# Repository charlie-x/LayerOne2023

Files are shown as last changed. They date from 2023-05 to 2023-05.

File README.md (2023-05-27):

# LayerOne2023

# Hardware

PIC16F1455

WS2812B/SK6812

# Software Needed

Microchip MPLAB 6.10

  https://www.microchip.com/en-us/tools-resources/develop/mplab-x-ide
  
XC8 2.41

  https://www.microchip.com/en-us/tools-resources/develop/mplab-xc-compilers/downloads-documentation#XC8

# DFU mode bootloader

 Badge has a DFU loader, hold the button down while plugging in USB should appear as device
 In Windows use ZADIG https://github.com/pbatard/libwdi/releases/download/v1.5.0/zadig-2.8.exe to change the driver to WinUSB device ID will be 1209:2002
 Modified Bootloader code is at https://github.com/charlie-x/PIC16F1455_Bootloader full fork https://github.com/charlie-x/PIC16F1455_Bootloader with tools
 
# dfu-utils to upload to badge
 
 convert hex file from Bootloader MPLAB project ( must use the HTxxxxxx_BootLoader version )
 
 get 454hex2dfu here https://github.com/charlie-x/PIC16F1-USB-DFU-Bootloader/tree/master/tools 
 
  454hex2dfu input.hex OKBBPIC_firmware.production.dfu
 
 put badge in DFU mode by holding button down and plugging into usb. (only when L1 bootloader is installed, if its overwritten you have to reinstall it with a PIC programmer like the pickkit3)
 
  dfu-util  -l -D OKBBPIC_firmware.production.dfu -R
 
# Optional Programmer

Pickit 3 or better , Pickit 2 supports CU with 3rd party sofware ,3 or 4 is recommended.

# badge competition

there is a very partial rubberducky 2.0 script commented out in the code, whoever makes it run duckyscript first, wins the single prize. claim with charliex, mmca or datagram.

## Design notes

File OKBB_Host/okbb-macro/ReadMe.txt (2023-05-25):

================================================================================
    MICROSOFT FOUNDATION CLASS LIBRARY : okbb-macro Project Overview
===============================================================================

The application wizard has created this okbb-macro application for
you.  This application not only demonstrates the basics of using the Microsoft
Foundation Classes but is also a starting point for writing your application.

This file contains a summary of what you will find in each of the files that
make up your okbb-macro application.

okbb-macro.vcxproj
    This is the main project file for VC++ projects generated using an application wizard.
    It contains information about the version of Visual C++ that generated the file, and
    information about the platforms, configurations, and project features selected with the
    application wizard.

okbb-macro.vcxproj.filters
    This is the filters file for VC++ projects generated using an Application Wizard. 
    It contains information about the assciation between the files in your project 
    and the filters. This association is used in the IDE to show grouping of files with
    similar extensions under a specific node (for e.g. ".cpp" files are associated with the
    "Source Files" filter).

okbb-macro.h
    This is the main header file for the application.  It includes other
    project specific headers (including Resource.h) and declares the
    COKBBmacroApp application class.

okbb-macro.cpp
    This is the main application source file that contains the application
    class COKBBmacroApp.

okbb-macro.rc
    This is a listing of all of the Microsoft Windows resources that the
    program uses.  It includes the icons, bitmaps, and cursors that are stored
    in the RES subdirectory.  This file can be directly edited in Microsoft
    Visual C++. Your project resources are in 1033.

res\okbb-macro.ico
    This is an icon file, which is used as the application's icon.  This
    icon is included by the main resource file okbb-macro.rc.

res\okbbmacro.rc2
    This file contains resources that are not edited by Microsoft
    Visual C++. You should place all resources not editable by
    the resource editor in this file.

/////////////////////////////////////////////////////////////////////////////

The application wizard creates one dialog class:

okbb-macroDlg.h, okbb-macroDlg.cpp - the dialog
    These files contain your CokbbmacroDlg class.  This class defines
    the behavior of your application's main dialog.  The dialog's template is
    in okbb-macro.rc, which can be edited in Microsoft Visual C++.

/////////////////////////////////////////////////////////////////////////////

Help Support:

hlp\okbbmacro.hhp
    This file is a help project file. It contains the data needed to
    compile the help files into a .chm file.

hlp\okbbmacro.hhc
    This file lists the contents of the help project.

hlp\okbbmacro.hhk
    This file contains an index of the help topics.

hlp\afxcore.htm
    This file contains the standard help topics for standard MFC
    commands and screen objects. Add your own help topics to this file.

makehtmlhelp.bat
    This file is used by the build system to compile the help files.

hlp\Images\*.gif
    These are bitmap files required by the standard help file topics for
    Microsoft Foundation Class Library standard commands.

/////////////////////////////////////////////////////////////////////////////

Other standard files:

StdAfx.h, StdAfx.cpp
    These files are used to build a precompiled header (PCH) file
    named okbb-macro.pch and a precompiled types file named StdAfx.obj.

Resource.h
    This is the standard header file, which defines new resource IDs.
    Microsoft Visual C++ reads and updates this file.

okbb-macro.manifest
	Application manifest files are used by Windows XP to describe an applications
	dependency on specific versions of Side-by-Side assemblies. The loader uses this
	information to load the appropriate assembly from the assembly cache or private
	from the application. The Application manifest  maybe included for redistribution
	as an external .manifest file that is installed in the same folder as the application
	executable or it may be included in the executable in the form of a resource.
/////////////////////////////////////////////////////////////////////////////

Other notes:

The application wizard uses "TODO:" to indicate parts of the source code you
should add to or customize.

If your application uses MFC in a shared DLL, you will need
to redistribute the MFC DLLs. If your application is in a language
other than the operating system's locale, you will also have to
redistribute the corresponding localized resources MFC100XXX.DLL.
For more information on both of these topics, please see the section on
redistributing Visual C++ applications in MSDN documentation.

/////////////////////////////////////////////////////////////////////////////

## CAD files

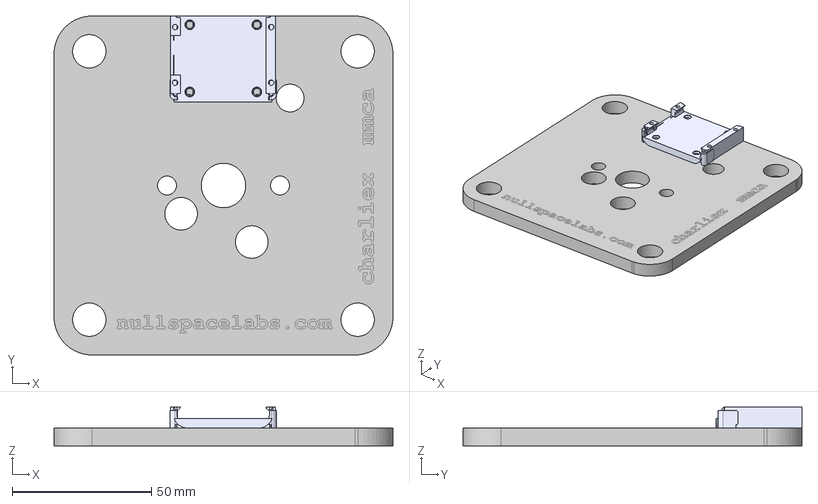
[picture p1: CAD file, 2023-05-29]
3MF/400_Percent_PCB_L1_2023.step
121.9 x 121.9 x 13.9 mm
4xPCB
USB_Bottom

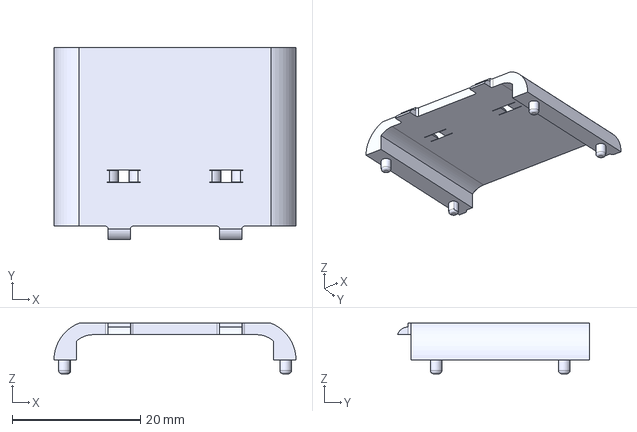
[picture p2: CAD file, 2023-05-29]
3MF/400_Percent_USB_L1_2023.step
37.8 x 30.0 x 7.92 mm

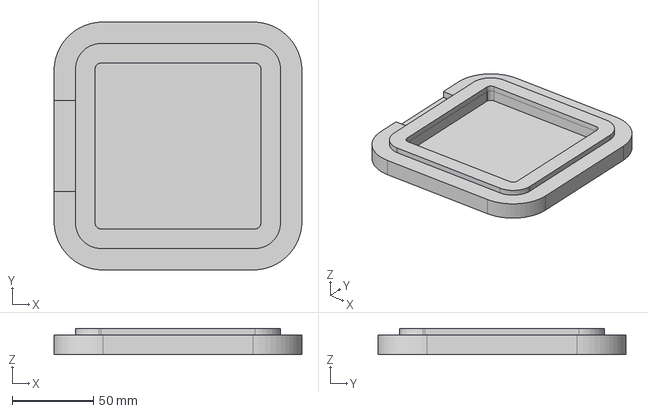
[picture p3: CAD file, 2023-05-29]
3MF/400_Percent_Logo_L1_2023.step
152.4 x 152.4 x 16.0 mm

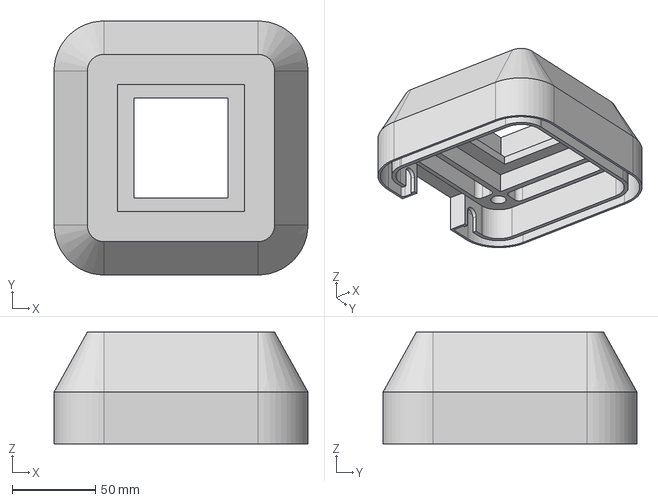
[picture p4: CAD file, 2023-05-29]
3MF/400_Percent_L1_2023_Case.step
152.4 x 152.4 x 67.2 mm

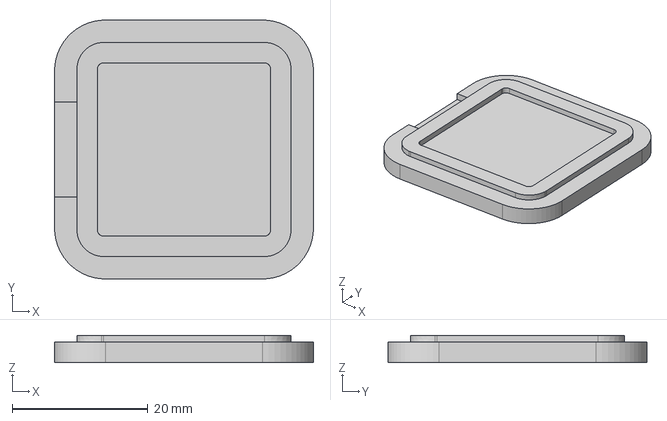
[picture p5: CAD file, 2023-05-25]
3MF/L1_Case 2 Part v5_Logo.step
38.1 x 38.1 x 4.00 mm

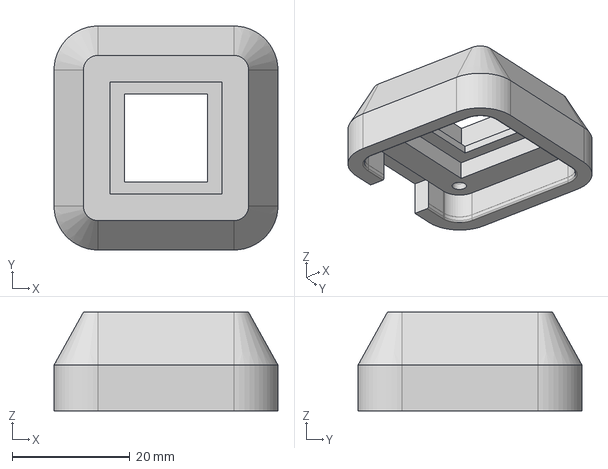
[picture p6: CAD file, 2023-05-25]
3MF/L1_Case 2 Part v5.step
38.1 x 38.1 x 16.8 mm

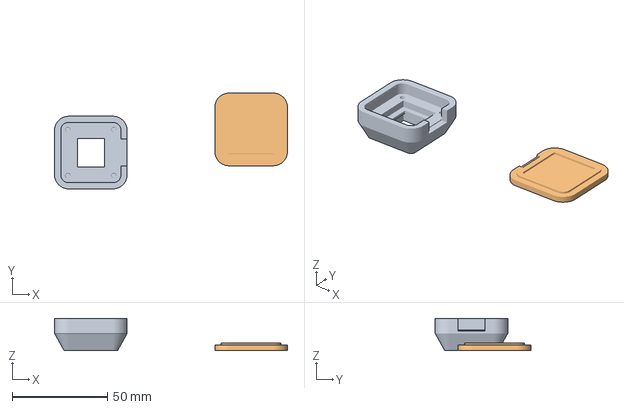
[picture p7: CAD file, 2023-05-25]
3MF/L1_2023.3mf
122.1 x 50.2 x 16.8 mm
L1_Case 2 Part v5.step
L1_Case 2 Part v5_Logo.step

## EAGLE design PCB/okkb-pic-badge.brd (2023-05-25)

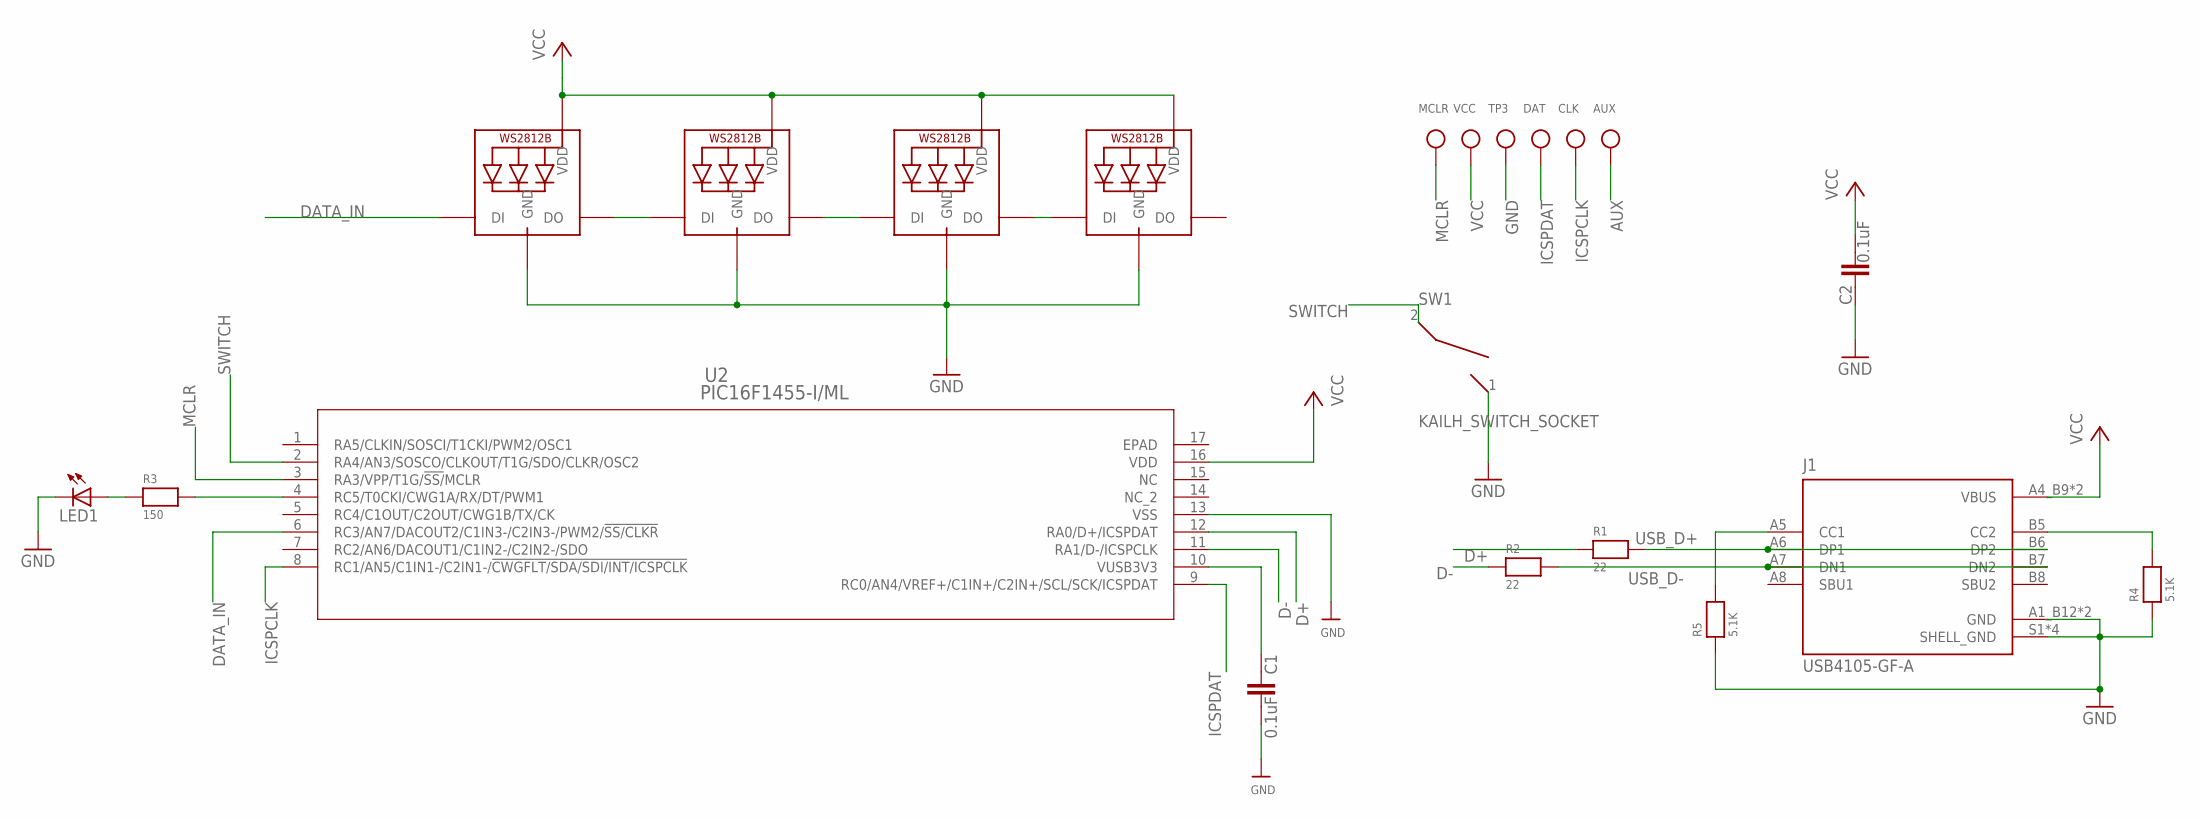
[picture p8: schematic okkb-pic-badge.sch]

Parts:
AUX: TESTPOINTROUND1MM; TESTPOINT_ROUND_1MM
C1, C2: 0.1uF; C0805
CLK: TESTPOINTROUND1MM; TESTPOINT_ROUND_1MM
DAT: TESTPOINTROUND1MM; TESTPOINT_ROUND_1MM
J1: USB4105-GF-A; GCT_USB4105-GF-A
LED1: LEDCHIPLED_1206; CHIPLED_1206
LED2, LED3, LED4, LED5: WS2812B3535; LED3535
MCLR: TESTPOINTROUND1MM; TESTPOINT_ROUND_1MM
R1, R2: 22; 0805
R3: 150; _0805
R4, R5: 5.1K; 0805
SW1: KAILH_SWITCH_SOCKET; SWITCH_SOCKET
TP3: TESTPOINTROUND1MM; TESTPOINT_ROUND_1MM
U2: PIC16F1455-I/ML; QFN16_4X4MC
VCC: TESTPOINTROUND1MM; TESTPOINT_ROUND_1MM

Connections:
AUX: AUX.P$1
D+: R1.1, U2.12 (RA0/D+/ICSPDAT)
D-: R2.1, U2.11 (RA1/D-/ICSPCLK)
DATA_IN: LED2.1 (DI), U2.6 (RC3/AN7/DACOUT2/C1IN3-/C2IN3-/PWM2/!SS/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)
GND: C1.2, C2.1, J1.A1_B12 (GND), J1.B1_A12 (GND), J1.S1 (SHELL_GND), J1.S2 (SHELL_GND), J1.S3 (SHELL_GND), J1.S4 (SHELL_GND), LED1.C, LED2.4 (GND), LED3.4 (GND), LED4.4 (GND), LED5.4 (GND), R4.1, R5.1, SW1.1 (2), TP3.P$1, U2.13 (VSS)
ICSPCLK: CLK.P$1, U2.8 (RC1/AN5/C1IN1-/C2IN1-/!CWGFLT/SDA/SDI/I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)
ICSPDAT: DAT.P$1, U2.9 (RC0/AN4/VREF+/C1IN+/C2IN+/SCL/SCK/ICSPD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)
MCLR: MCLR.P$1, U2.3 (RA3/VPP/T1G/!SS/!MCLR)
unnamed: R3.2, U2.4 (RC5/T0CKI/CWG1A/RX/DT/PWM1)
unnamed: LED1.A, R3.1
unnamed: C1.1, U2.10 (VUSB3V3)
unnamed: LED2.3 (DO), LED3.1 (DI)
unnamed: LED3.3 (DO), LED4.1 (DI)
unnamed: LED4.3 (DO), LED5.1 (DI)
unnamed: J1.A5 (CC1), R5.2
unnamed: J1.B5 (CC2), R4.2
SWITCH: SW1.2 (1), U2.2 (RA4/AN3/SOSCO/CLKOUT/T1G/SDO/CLKR/OSC2)
USB_D+: J1.A6 (DP1), J1.B6 (DP2), R1.2
USB_D-: J1.A7 (DN1), J1.B7 (DN2), R2.2
VCC: C2.2, J1.A4_B9 (VBUS), J1.B4_A9 (VBUS), LED2.2 (VDD), LED3.2 (VDD), LED4.2 (VDD), LED5.2 (VDD), U2.16 (VDD), VCC.P$1

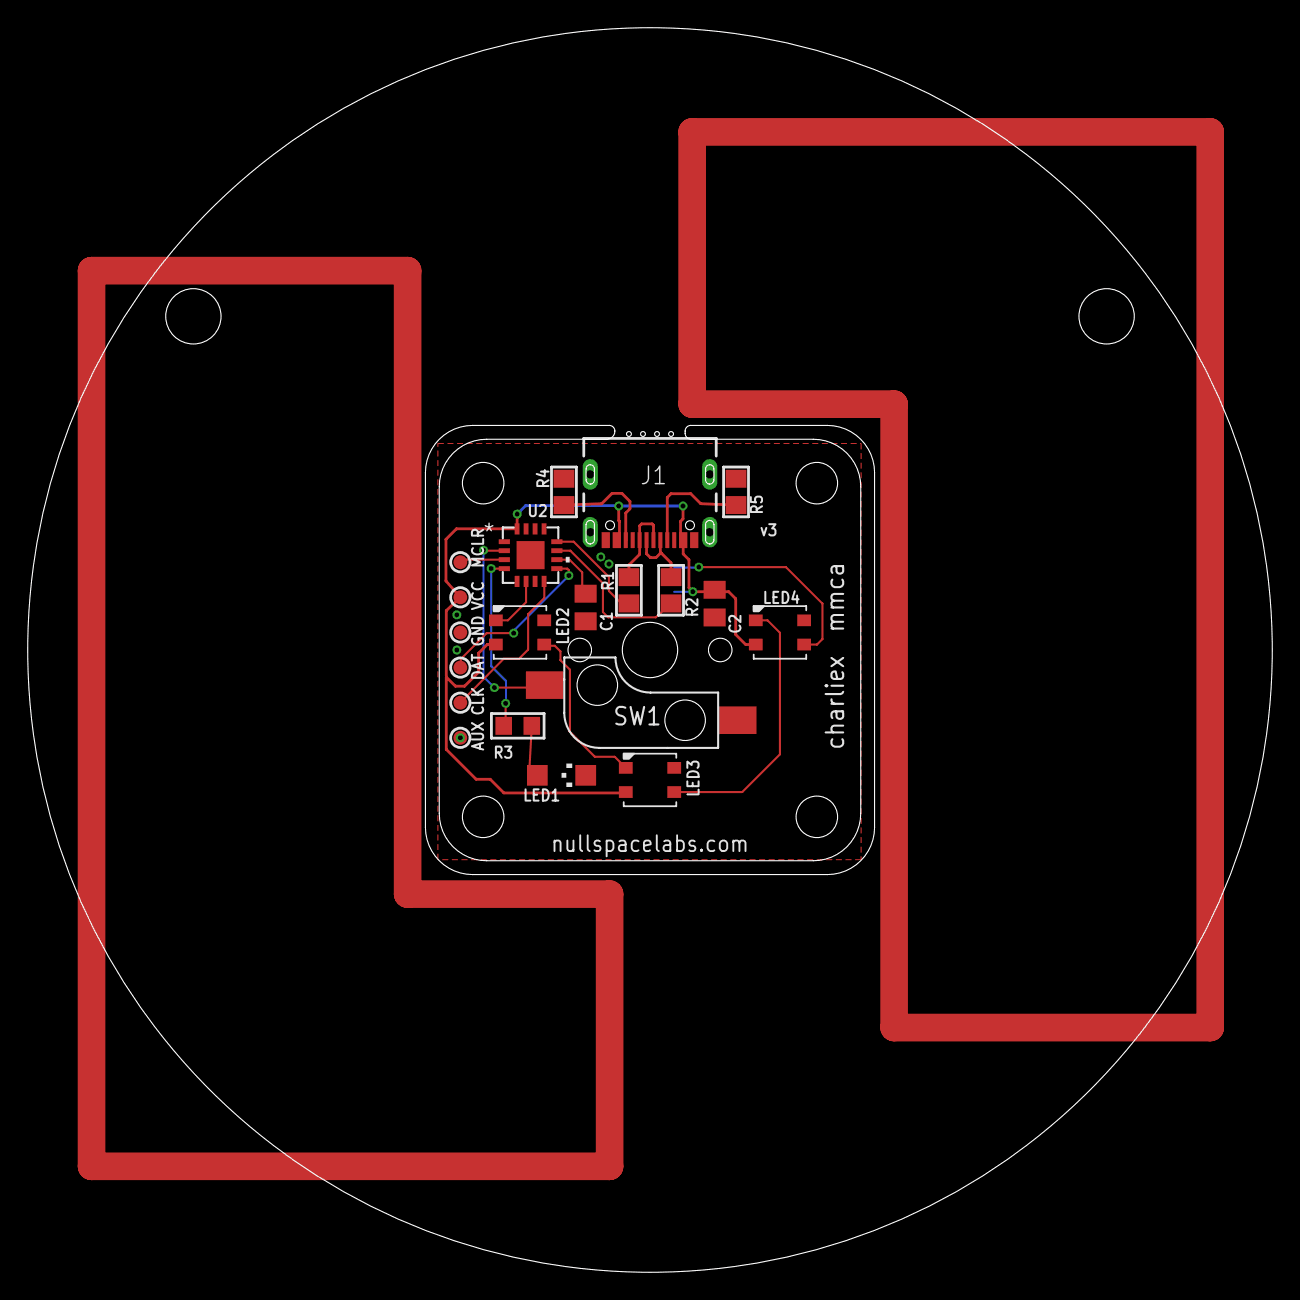
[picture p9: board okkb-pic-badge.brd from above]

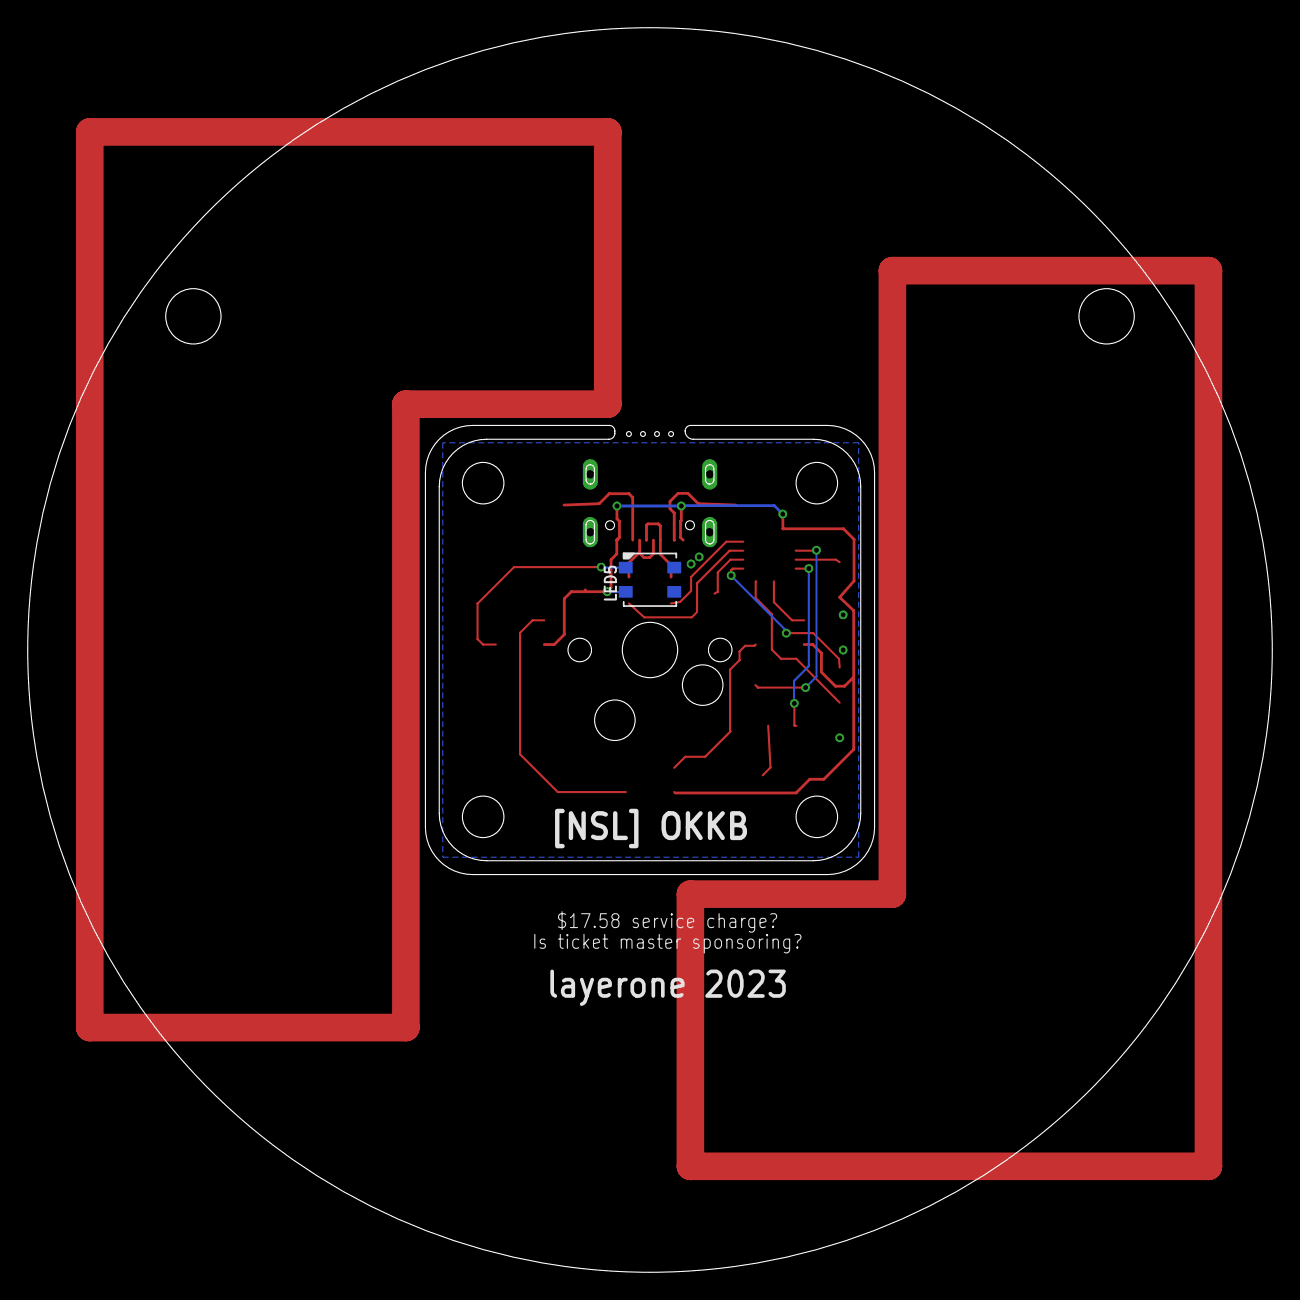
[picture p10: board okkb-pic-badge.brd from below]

Board: 2 copper layers, 90.0 x 90.0 mm, 21 parts (2 on the bottom side), 19 nets.

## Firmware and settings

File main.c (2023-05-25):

////////////////////////////////////////////
// LayerOne 2023 revision of OKBB firmware//
////////////////////////////////////////////

// LayerOne 2023
// Use HT_PIC16F54_BootLoader version for DFU load


#include <xc.h>
#include <math.h>
#include <stdio.h>
#include "HEFlash.h"
#include "Usb.h"
#include "ws2812.h"
#include "scan_codes.h"
#include "keyboard.h"


// --ROM=default,-1f80-1fff for Flash
// default,0-1FF,1F7F-1F7F for BootLoader

__IDLOC ( 4D8A );

// there is a bootloader, but we don't know where it is
#ifndef USE_BOOTLOADER

// don't need this in bootloader mode
// CONFIG1
#pragma config FOSC = INTOSC    // Oscillator Selection Bits (INTOSC oscillator: I/O function on CLKIN pin)
#pragma config WDTE = OFF       // Watchdog Timer Enable (WDT disabled)
#pragma config PWRTE = OFF      // Power-up Timer Enable (PWRT disabled)
#pragma config MCLRE = OFF      // MCLR Pin Function Select (MCLR/VPP pin function is Digital Input)
#pragma config CP = OFF         // Flash Program Memory Code Protection (Program memory code protection is disabled)
#pragma config BOREN = ON       // Brown-out Reset Enable (Brown-out Reset enabled)
#pragma config CLKOUTEN = OFF   // Clock Out Enable (CLKOUT function is disabled. I/O or oscillator function on the CLKOUT pin)
#pragma config IESO = OFF       // Internal/External Switchover Mode (Internal/External Switchover Mode is enabled)
#pragma config FCMEN = OFF      // Fail-Safe Clock Monitor Enable (Fail-Safe Clock Monitor is enabled)

// CONFIG2
#pragma config WRT = OFF        // Flash Memory Self-Write Protection (Write protection off)
#pragma config CPUDIV = NOCLKDIV // CPU System Clock Selection Bit (CPU system clock divided by 6)
#pragma config USBLSCLK = 48MHz // USB Low SPeed Clock Selection bit (System clock expects 48 MHz, FS/LS USB CLKENs divide-by is set to 8.)
#pragma config PLLMULT = 3x     // PLL Multipler Selection Bit (3x Output Frequency Selected)
#pragma config PLLEN = ENABLED  // PLL Enable Bit (3x or 4x PLL Enabled)
#pragma config STVREN = ON      // Stack Overflow/Underflow Reset Enable (Stack Overflow or Underflow will cause a Reset)
#pragma config BORV = LO        // Brown-out Reset Voltage Selection (Brown-out Reset Voltage (Vbor), low trip point selected.)
#pragma config LPBOR = OFF      // Low-Power Brown Out Reset (Low-Power BOR is disabled)
#pragma config LVP = ON        // Low-Voltage Programming Enable (Low-voltage programming enabled)

#endif

// const data of a breathe in/out ramp for the key led
static const unsigned char breathe[] = {
    1, 1, 2, 7, 15, 25, 39, 54, 72, 91, 111, 131, 151, 171, 189, 206,
    221, 234, 243, 250, 254, 254, 251, 245, 236, 225, 210, 194, 176,
    156, 136, 116, 96, 77, 59, 43, 29, 17, 9, 3, 1, 1
};

// Local Variables
static BYTE buttonStatus; // This is to hold last status of the button so that we only report if it changes
static BYTE ledState;

// status of modifier keys
static BYTE modifierKeys = 0;

static BYTE mode = 0;

// 32 bytes * 4 =128
static uint8_t flashBuffer[ FLASH_ROWSIZE * 4 ];

// interrupt driven counter ( needs to be calibrated)
volatile uint32_t microseconds = 0;

// Interrupt

// xc8 doesn't like interrupt keyword
// void interrupt ISRCode()
void interrupt ISRCode()
{
    if (INTCONbits.TMR0IF) {
        microseconds += 1; // With 1:16 pre-scaler and FOSC/4 clock source, Timer0 increments every 8 microseconds
        TMR0 = 0; // Reset Timer0 value
        INTCONbits.TMR0IF = 0; // Clear Timer0 interrupt flag
    }

    if ( UsbInterrupt ) {
        ProcessUSBTransactions();
    }
}

static void InitializeSystem ( void )
{
    ANSELA = 0x00;
    ANSELC = 0x00;
    OSCTUNE = 0x00;
    OSCCON = 0xFC; // 16MHz HFINTOSC with 3x PLL enabled (48MHz operation)
    ACTCON = 0x90; // Enable active clock tuning with USB
    OPTION_REG = 0xC3; // Set pre-scaler to 256
    
/*
    Pinouts for peripherals
 *
    #define WS2812              RC3
    #define Button              RA4 // RA4 for new version
    #define Led                 RC5
    
*/
    TRISC = 0b00010000; // Set RC3 as output (WS2812) except RA4 for Button
    
    // TRISCbits.TRISC4 = 0b1;
    OPTION_REGbits.nWPUEN = 0;
    
    ////WPUA = 0b00010000;
    WPUAbits.WPUA4 = 0b1;
    buttonStatus = 0;
    LATC = 0b00000000; // Clear Port C Latches;
    
    TMR0 = 0; // Reset Timer0 value
    INTCONbits.TMR0IE = 1; // Enable Timer0 interrupt
    INTCONbits.TMR0IF = 0; // Clear Timer0 interrupt flag
    INTCONbits.PEIE = 1; // Enable peripheral interrupts
    INTCONbits.GIE = 1; // Enable global interrupts
}

static void EnableInterrupts ( void )
{
    UIE = 0x4B; // Transaction complete, Start Of Frame, Error, Reset
    INTCONbits.PEIE = 1; // Peripheral Interrupt enable
    INTCONbits.GIE = 1; // Global Interrupt Enable
    PIE2bits.USBIE = 1; // Enable USB Global Interrupt
}

BYTE getLEDstate ( void )
{
    return ledState;
}

BYTE getMODstate(void)
{
    return modifierKeys;
}

void ProcessIncommingKbdData ( void )
{
    // Windows Will send only a single Byte
    // with statuses of LEDs
    // first bit for NUM lock, second for caps etc..

    modifierKeys = keyboardRXBuffer[0];
    
    Led = ( modifierKeys & 0x01 );
}

void ProcessIncommingHidData ( void )
{
    BYTE i;

    switch ( controlRXBuffer[0] ) {

        case 0xF0:

            Red[3] = controlRXBuffer[10];
            Green[3] = controlRXBuffer[11];
            Blue[3] = controlRXBuffer[12];

        case 0xF1:

            Red[0] = controlRXBuffer[1];
            Green[0] = controlRXBuffer[2];
            Blue[0] = controlRXBuffer[3];

            Red[1] = controlRXBuffer[4];
            Green[1] = controlRXBuffer[5];
            Blue[1] = controlRXBuffer[6];

            Red[2] = controlRXBuffer[7];
            Green[2] = controlRXBuffer[8];
            Blue[2] = controlRXBuffer[9];

            break;

        case 0xF2:

            Red[3] = controlRXBuffer[1];
            Green[3] = controlRXBuffer[2];
            Blue[3] = controlRXBuffer[3];

            break;

        // writes out all the flash memory 128 bytes
        case 0xfd:
            HEFLASH_writeBlock ( 1, flashBuffer,  FLASH_ROWSIZE );
            HEFLASH_writeBlock ( 2, &flashBuffer[ FLASH_ROWSIZE * 2], FLASH_ROWSIZE );
            HEFLASH_writeBlock ( 3, &flashBuffer[ FLASH_ROWSIZE * 3], FLASH_ROWSIZE );
            HEFLASH_writeBlock ( 4, &flashBuffer[ FLASH_ROWSIZE * 4], FLASH_ROWSIZE );
            break;
            


        case 0xfe:
            // buffer is cmd = 0xfe, offset*8, 8 bytes of data

            // calculate offset  n * 8
            {
                unsigned char multiplier = controlRXBuffer[1];
                unsigned int offset = (unsigned int)multiplier * 8;

                for ( i = 0; i < 8; i++ ) {
                    flashBuffer[ ( offset ) + i ] = (unsigned char)controlRXBuffer[ 2 + i ];
                }
            }
            break;

        case 0xff:

            for ( i = 0; i < 15; i++ ) {
                flashBuffer[15 + i] = (unsigned char)controlRXBuffer[ 1 + i ];
            }

            flashBuffer[ FLASH_ROWSIZE - 1 ] = 0;

            break;

        default:

            // Windows Will send only a single byte
            // with statuses of LED
            // first bit for NUM lock, second for CAPS lock etc..
            Led = ((unsigned int)controlRXBuffer[0] & 0x01 );

            ledState = Led;

            break;
    }

    OutputLEDDataStream();
}

void PrepareHidTxBuffer ( void )
{
    BYTE i;

    controlTXBuffer[0] = 0x80; // Status
    controlTXBuffer[1] = Button; // Button Status
    controlTXBuffer[2] = Led; // Led Status
    controlTXBuffer[3] = 0x00; // Empty Byte

    // Keyboard
    for ( i = 3; i < 0x10; i++ ) {
        controlTXBuffer[i] = flashBuffer[i - 3];
    }
}

static void CheckUsb ( void )
{
    if ( IsUsbDataAvaialble ( HidInterfaceNumber ) > 0 ) {
        ProcessIncommingHidData();
        PrepareHidTxBuffer();
        ReArmInterface ( HidInterfaceNumber );

        while ( HIDSend ( HidInterfaceNumber ) == 0 );

    }

    if ( IsUsbDataAvaialble ( KbdInterfaceNumber ) > 0 ) {
        ProcessIncommingKbdData();
        ReArmInterface ( KbdInterfaceNumber );
    }
}

// correct sequence to mimic
//
// 04 00 00 00 00 00 00 00 ALT KEY PRESS
// 04 00 57 00 00 00 00 00 KPPLUS
// 04 00 00 00 00 00 00 00 KPPLUS UP
// 04 00 1F 00 00 00 00 00 KEY 2
// 04 00 00 00 00 00 00 00 KEY 2 UP
// 04 00 22 00 00 00 00 00 KEY 5
// 04 00 00 00 00 00 00 00 KEY 5 UP
// 04 00 25 00 00 00 00 00 KEY 8
// 04 00 00 00 00 00 00 00 KEY 8 UP
// 04 00 21 00 00 00 00 00 KEY 4
// 04 00 00 00 00 00 00 00 KEY 4 UP
// 00 00 00 00 00 00 00 00 ALT KEY UP

// Convert our Unicode WORD value to key codes
//


void pressKeyLALT2 ( unsigned short value )
{
    BYTE lo, hi;

    hi = value >> 8;
    lo = value;

    pressKeyOnly ( 0, 0, 0, 0, 0, 0, 0 );

#define DELAY __delay_ms(55)

    pressKeyOnly ( KEY_MOD_LALT, 0, 0, 0, 0, 0, 0 );


    pressKeyOnly ( KEY_MOD_LALT, KEY_KPPLUS, 0, 0, 0, 0, 0 );
    pressKeyOnly ( KEY_MOD_LALT, 0, 0, 0, 0, 0, 0 );

    pressKeyOnly ( KEY_MOD_LALT, value2hex ( hi >> 4 ), 0, 0, 0, 0, 0 );
    pressKeyOnly ( KEY_MOD_LALT, 0, 0, 0, 0, 0, 0 );

    pressKeyOnly ( KEY_MOD_LALT, value2hex ( hi & 0xf ), 0, 0, 0, 0, 0 );
    pressKeyOnly ( KEY_MOD_LALT, 0, 0, 0, 0, 0, 0 );

    pressKeyOnly ( KEY_MOD_LALT, value2hex ( lo >> 4 ), 0, 0, 0, 0, 0 );
    pressKeyOnly ( KEY_MOD_LALT, 0, 0, 0, 0, 0, 0 );

    pressKeyOnly ( KEY_MOD_LALT, value2hex ( lo & 0xf ), 0, 0, 0, 0, 0 );

    pressKeyOnly ( 0, 0, 0, 0, 0, 0, 0 );

    DELAY;

#if 0

    controlTXBuffer[0] = value2hex ( hi >> 4 );
    controlTXBuffer[1] = value2hex ( hi & 0xf );
    controlTXBuffer[2] = value2hex ( lo >> 4 );
    controlTXBuffer[3] = value2hex ( lo & 0xf );

    controlTXBuffer[4] = hi >> 4;
    controlTXBuffer[5] = hi & 0xf;
    controlTXBuffer[6] = lo >> 4;
    controlTXBuffer[7] = lo & 0xf;


    controlTXBuffer[8] = 0xEE;
    controlTXBuffer[9] = 0xEE;
    controlTXBuffer[10] = 0xEE;
    controlTXBuffer[11] = 0xEE;
    controlTXBuffer[12] = 0xEE;
    controlTXBuffer[13] = 0xEE;
    controlTXBuffer[14] = 0xEE;
    controlTXBuffer[15] = 0xEE;


    ReArmInterface ( HidInterfaceNumber );

    while ( HIDSend ( HidInterfaceNumber ) == 0 );

#endif

}

void ProcessIO ( void )
{
    // check USB for incoming Commands
    if ( IsUsbReady ) {
        CheckUsb();
    }

    // check status of the button
    if ( Button == buttonStatus ) {
        return;
    }

    if ( !Button ) {

        // needs, (seems to miss first key if we don't do this)
        pressKey ( 0, 0, 0, 0, 0, 0, 0 );

        if ( flashBuffer[0] != 0xff ) {

            print ( flashBuffer );

        } else {

            //check if flash buffer isn't initialised  (otherwise custom message) 
            switch ( flashBuffer[1] ) {

                case 0:
                case 0xff:
#if SEND_MOD_STATUS
                {
                        char buffer[10];
                        sprintf(buffer," 0x%x ",getMODstate());
                        print(buffer);
                   }
#endif

                   // default string stored to send back to host
                   print("LayerOne 2023");

#if 0
                    // send a shruggie, needs the OS to be able to handle unicode input though
                    //
                    pressKeyLALT2 ( 0x02c9 ); //KEY_0,KEY_2,KEY_C,KEY_9 ); // 9 18
                    //pressKeyLALT2 ( 0x005c ); //KEY_0,KEY_0,KEY_5,KEY_C ); // 9 18
                    //pressKeyLALT2 ( 0x005f ); //KEY_0,KEY_0,KEY_5,KEY_F ); // 9 18
                    print ( " \\_(" );
                    //pressKeyLALT2 ( 0x0028 ); //KEY_0,KEY_0,KEY_2,KEY_8 ); // 9 18
                    pressKeyLALT2 ( 0x30c4 ); //KEY_3,KEY_0,KEY_C,KEY_4 ); // 9 18
                    //pressKeyLALT2 ( 0x0029 ); //KEY_0,KEY_0,KEY_2,KEY_9 ); // 9 18
                    //pressKeyLALT2 ( 0x005f ); //KEY_0,KEY_0,KEY_5,KEY_F ); // 9 18
                    print ( " )_/" );
                    //pressKeyLALT2 ( 0x002f ); //KEY_0,KEY_0,KEY_2,KEY_F ); // 9 18
                    pressKeyLALT2 ( 0x02c9 ); //KEY_0,KEY_2,KEY_C,KEY_9 ); // 9 18
#endif
                    
#if 0
                    //alt version
                    // hand
                    //pressKeyLALT ( KEY_0, KEY_2, KEY_C, KEY_9);
                    pressKeyLALT2 ( 0x2c9 );

                    // 0x27, 0x1f , 0x06, 0x26

                    // doesn't need (maybe)
                    // pressKey(0,0,0,0,0,0,0);

                    // arm+ partial face
                    print ( "\\\_\(" );

                    // face
                    //pressKeyLALT (  KEY_3, KEY_0, KEY_C, KEY_4 );
                    pressKeyLALT2 ( 0x30c4 );

                    // does need
                    //pressKey ( 0, 0, 0, 0, 0, 0, 0 );

                    // end of face, beginning of last arm
                    print ( ")_/" );

                    // last hand
                    //pressKeyLALT ( KEY_0, KEY_2, KEY_C, KEY_9);
                    pressKeyLALT2 ( 0x2c9 );
#endif
                    break;

                case 1:

                    print ( "( " );

                    pressKeyLALT2 ( 0x0361 );
                    pressKeyLALT2 ( 0x00B0 );
                    print ( " " );
                    pressKeyLALT2 ( 0x035C );
                    pressKeyLALT2 ( 0x0296 );
                    print ( " " );
                    pressKeyLALT2 ( 0x0361 );
                    pressKeyLALT2 ( 0x00B0 );
                    print ( ")" );


                    break;

                case 2: {

                        unsigned char  length;

                        // get the number of key sets
                        length = flashBuffer[2];

                        for ( unsigned char i = 0; i < length; i++ ) {

                            pressKeyLALT2 (

                                ( flashBuffer[ 3 + ( ( i * 2 ) + 0 ) ] << 8 ) +
                                flashBuffer[ 3 + ( ( i * 2 ) + 1 ) ]

                            );
                        }
                    }
                    break;
            }
        }

        // needs
        // pressKey ( 0, 0, 0, 0, 0, 0, 0 );
        
        // this delay might help with ghosting/debounce ( add a real debounce pls )
        // not really
        
        __delay_ms ( 1 );
    }

    // Save New Button Status
    buttonStatus = Button;
}

void main ( void )
{
    unsigned int r, index;
    unsigned long counter2 = 0, counter = 0;

    InitializeSystem();
    InitializeUSB();
    EnableUSBModule();
    EnableInterrupts();

    r = FLASH_readConfig ( 0x8000 );

    r = HEFLASH_readBlock ( flashBuffer, 1, FLASH_ROWSIZE );
    r = HEFLASH_readBlock ( &flashBuffer[FLASH_ROWSIZE], 2, FLASH_ROWSIZE );
    r = HEFLASH_readBlock ( &flashBuffer[FLASH_ROWSIZE * 2], 3, FLASH_ROWSIZE );
    r = HEFLASH_readBlock ( &flashBuffer[FLASH_ROWSIZE * 3], 4, FLASH_ROWSIZE );

    
    // run the LEDS, then process the usb io -- software counts... 
    while ( 1 ) {

        switch ( mode ) {

            case LED_COLORWHEEL:


                if ( counter == 20000 ) {
                    ColorWheel ( 100 );
                    counter = 0;
                }

                counter++;


                break;

            case LED_SLOWFADE:

                if ( counter == 5000 ) {

                    if ( index >= sizeof ( breathe ) ) {
                        index = 0;
                    }
 
                        ColorWheel ( 1 );
 
                    r = breathe[index];

                    Red[3] = r;
                    Green[3] = r;
                    Blue[3] = r;

                    OutputLEDDataStream();

                    index++;

                    counter = 0;

                }

                counter++;
                break;

            default:

                mode = 0;
                break;
        }

        if ( microseconds > (5000*5UL) ) {
            counter2 = 0;
            counter = 0;
            mode++;
            microseconds = 0 ;
        }

        counter2++;

        ProcessIO();
    }
}

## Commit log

2023-05-25 Add files via upload
    adding eagle files
    [okkb-pic-badge.brd, okkb-pic-badge.sch]
2023-05-25 Add files via upload
    case 3MF files
    [L1_2023.3mf, L1_Case 2 Part v5.step, L1_Case 2 Part v5_Logo.step]

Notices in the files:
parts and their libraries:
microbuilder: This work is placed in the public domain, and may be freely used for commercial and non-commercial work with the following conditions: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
